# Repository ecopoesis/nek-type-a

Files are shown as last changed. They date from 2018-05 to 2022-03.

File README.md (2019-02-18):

# Natural Ergonomic Keyboard, Type A

One of the best keyboards ever made is the [Microsoft Natural Keyboard](https://en.wikipedia.org/wiki/Microsoft_Natural_Keyboard). 
Unfortunately modern versions of the natural keyboard are significantly worse then the original mid 90s versions. 
The goal of this project is to create a high-quality, open-source replacement for the natural keyboard.

Power by QMK

## Goals

* Standard split-QWERTY layout mirroring the Microsoft Natural Keyboards
* No built-in number pad
* High quality mechanical switches
* Bluetooth or USB connection
* Plug and play (no-solder) microcontroller replacement
* Heirloom quality

## Design

The keyboard (and repo) is divided into the following parts:

* Body
* Electronics

### Body

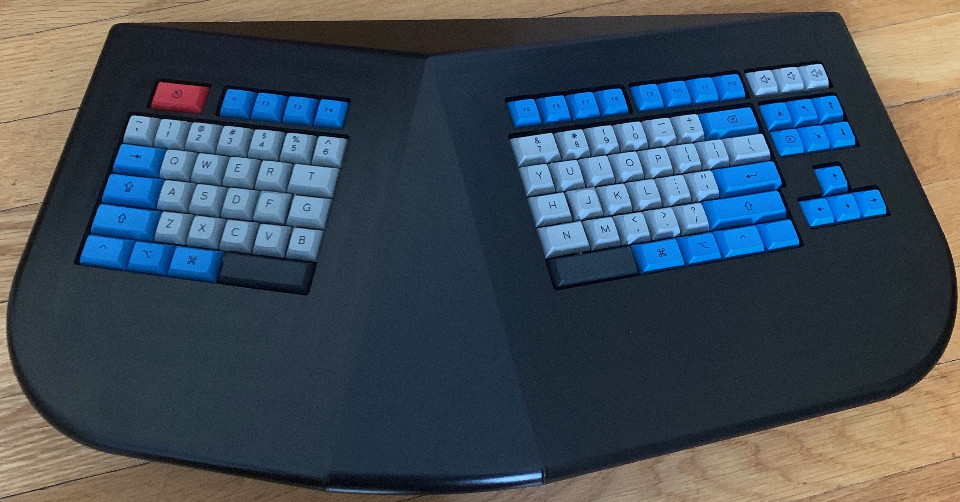
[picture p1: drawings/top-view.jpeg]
NEK Type A


The body has three major components: the aluminum unibody, the left and right steel switch plates and the acrylic access panel. 

Source files:
* `*.kbd.json` files are generated using the [keyboard_layout_editor.com](http://www.keyboard-layout-editor.com)
* `*.svg` and `*.dxf` files are built using [swillkb's Plate and Case Builder](http://builder.swillkb.com/) based on the `.kbd.json` files
  * The `*switch.*` files are the laser cutter templates
* `body.stl` and `body.step` are built from the [CadQuery](https://github.com/dcowden/cadquery) source file `body.py`. The easiest way to build this is to use the provided Docker image and `Makefile`:
  ```bash
    cd body && make
  ```    

You will need to have the following manufactured:
* Case
  * [`body.step`](body/target/body.step)
  * [screw tapping plan](drawings/bottom_view.pdf)
  * CNC from aluminum at [Xometry](http://xometry.com)
* Rubber gaskets
  * [`left_closed.dxf`](body/build_data/left_closed.dxf)
  * [`right_closed.dxf`](body/build_data/right_closed.dxf)
  * Laser cut from Buna-N Rubber 0.031 in at [Big Blue Saw](https://www.bigbluesaw.com/)
* Acrylic plate
  * [`plate.dxf`](drawings/plate.dxf)
  * Laser cut from Acrylic Plastic, Clear 0.118 in at [Big Blue Saw](https://www.bigbluesaw.com/)
* Steel plates
  * [`left_switch.dxf`](body/build_data/left_switch.dxf)
  * [`right_switch.dxf`](body/build_data/right_switch.dxf)
  * Laser cut from 304 Stainless Steel 1.5mm at [Lasergist](https://www.lasergist.com/)
  
You will need to buy:
* 8x M5x8mm screws
* 4x M5x20mm screws
* 3x M3 standoffs
* 3x M3x5mm screws
* 4x [M5 feet](https://www.amazon.com/gp/product/B000PWU9CC)
* 1x [USB-C panel mount](https://www.datapro.net/products/usb-c-panel-mount-extension-cable.html)
* 1x [19mm latching button](https://www.amazon.com/gp/product/B06XQZ3Y76)
* 1x [2-pin JST-XHP connector](https://www.amazon.com/gp/product/B0774TF39N)

### Electronics

The electronics are designed to be swappable. The left and right PCBs only contain the keyboard matrices and the ribbon connectors to the center PCB.

The PCBs can be made directly from the `BRD` files by [OSH Park](http://oshpark.com).

#### Left
[`left.brd`](eagle/nek-type-a/left.brd)

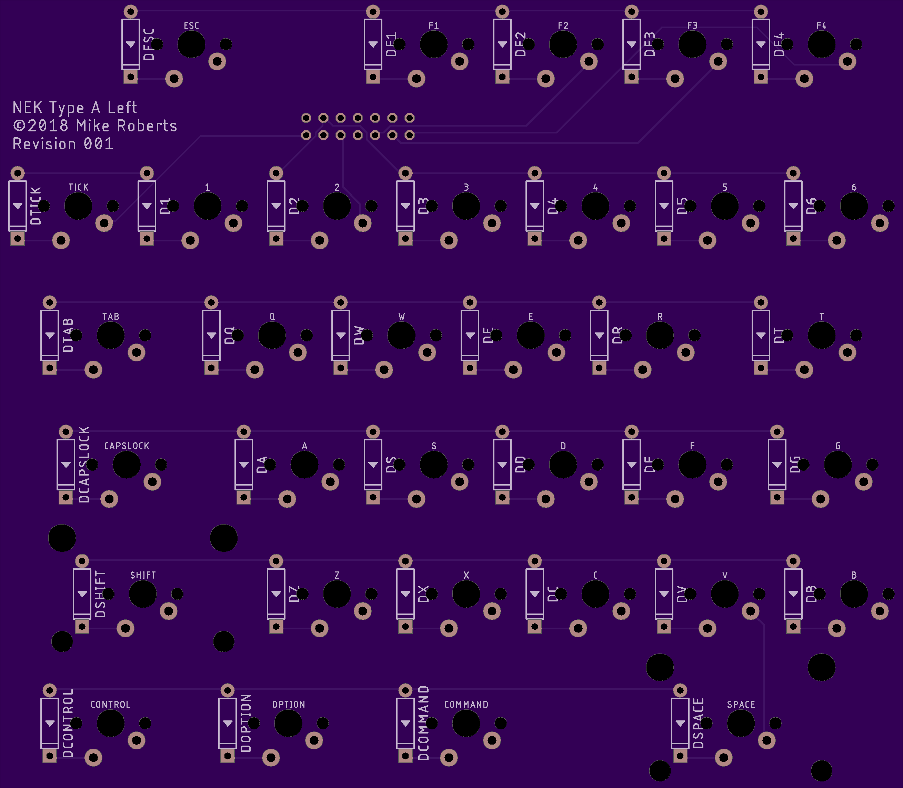
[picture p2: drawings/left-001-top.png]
Left PCB Rev 001 Top
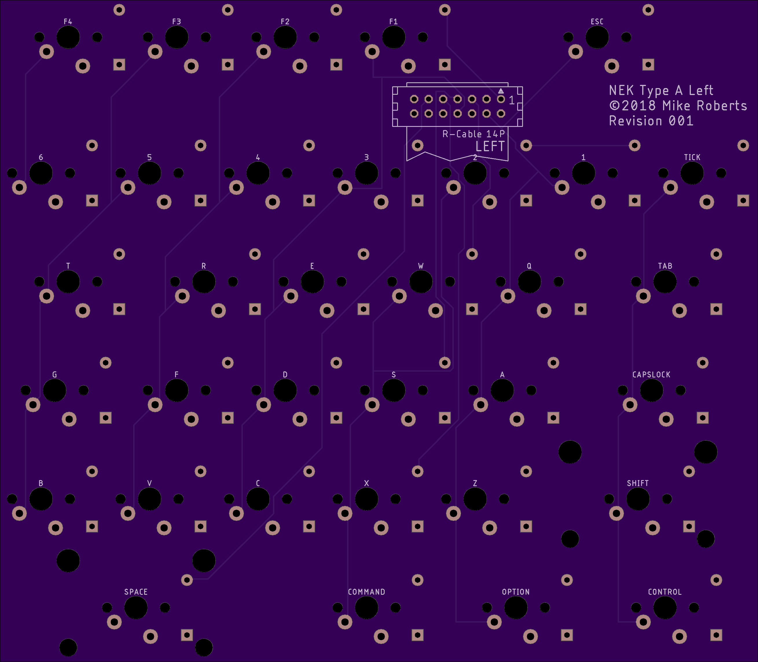
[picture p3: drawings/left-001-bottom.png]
Left PCB Rev 001 Bottom
 

#### Right
[`right.brd`](eagle/nek-type-a/right.brd)

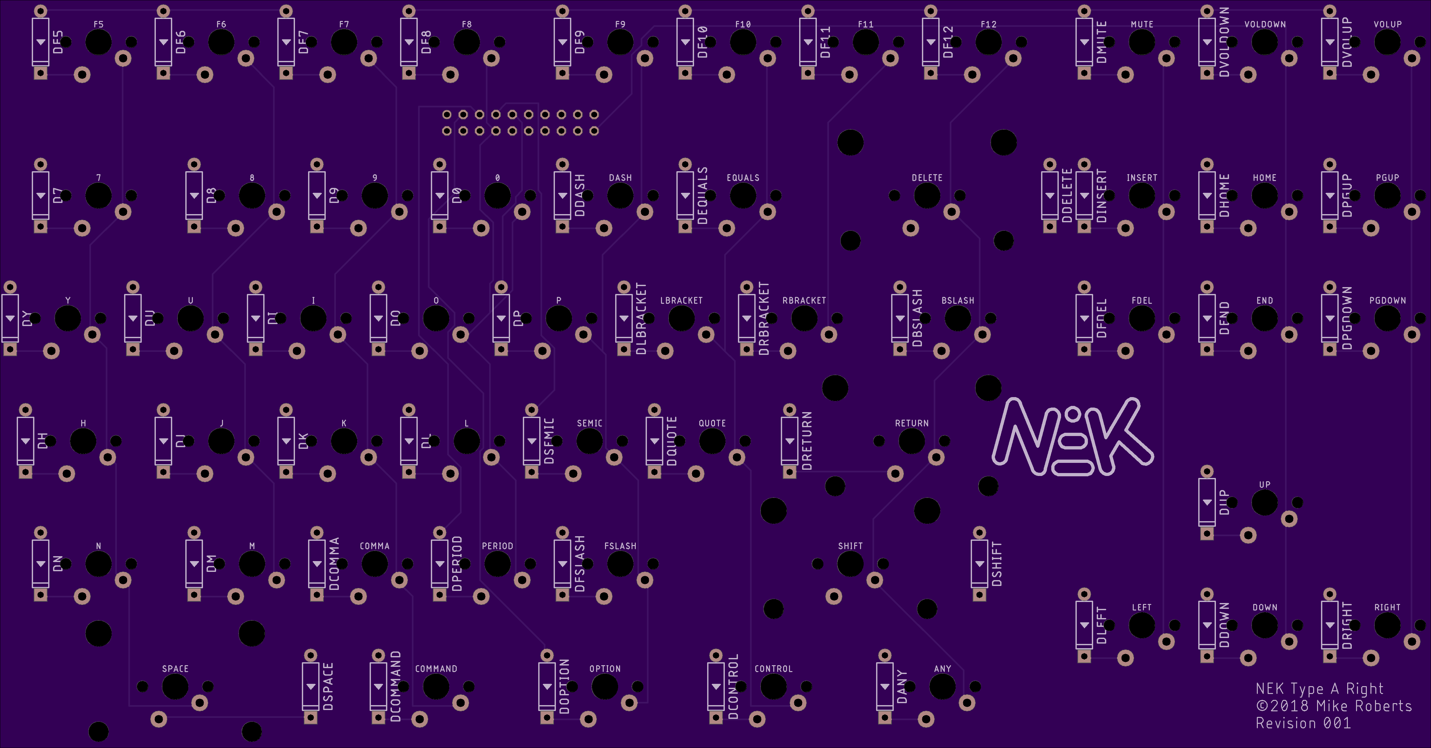
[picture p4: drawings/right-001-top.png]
Right PCB Rev 001 Top
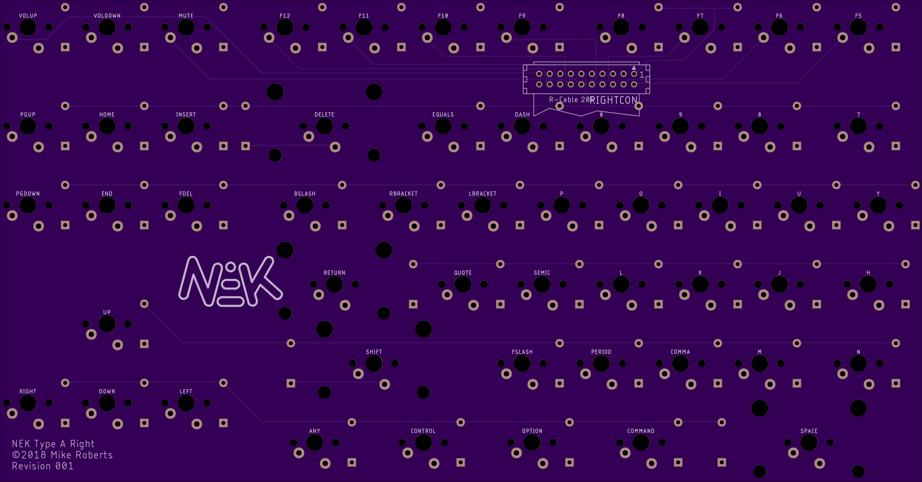
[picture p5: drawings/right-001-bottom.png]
Right PCB Rev 001 Bottom
 

#### Center
[`center.brd`](eagle/nek-type-a/center.brd)

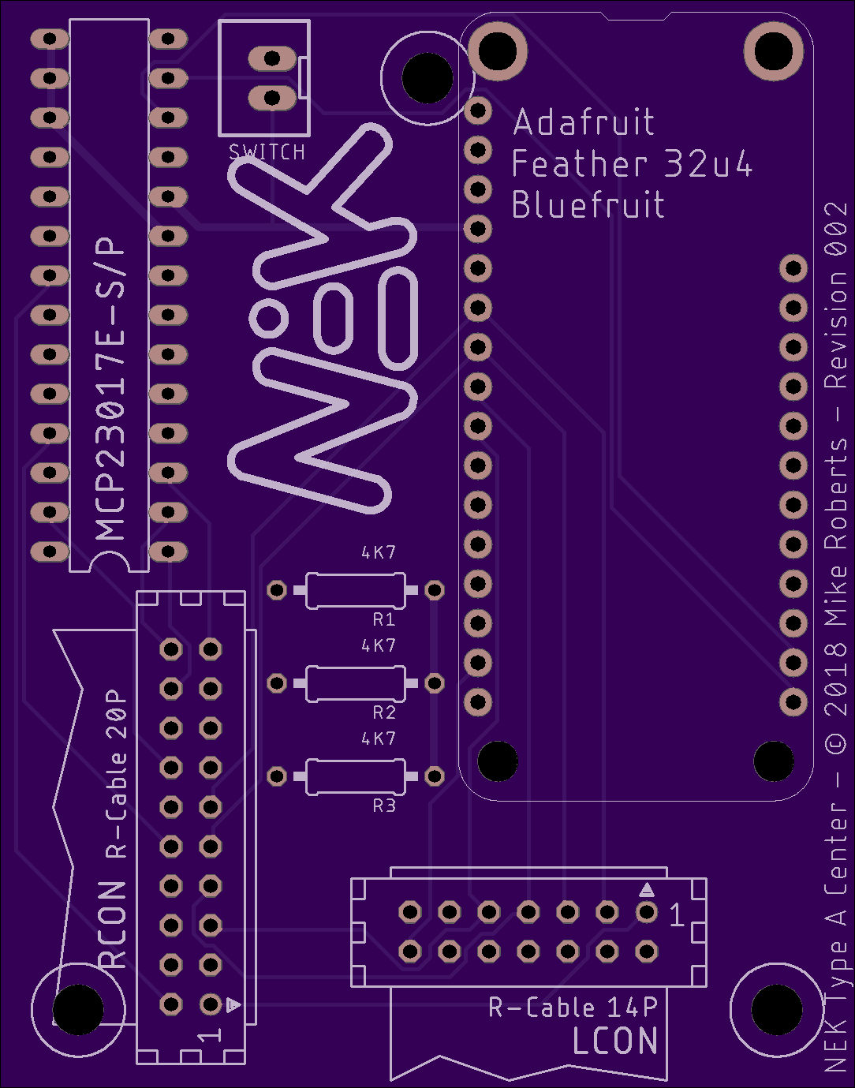
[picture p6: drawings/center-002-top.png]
Center PCB Rev 002 Top
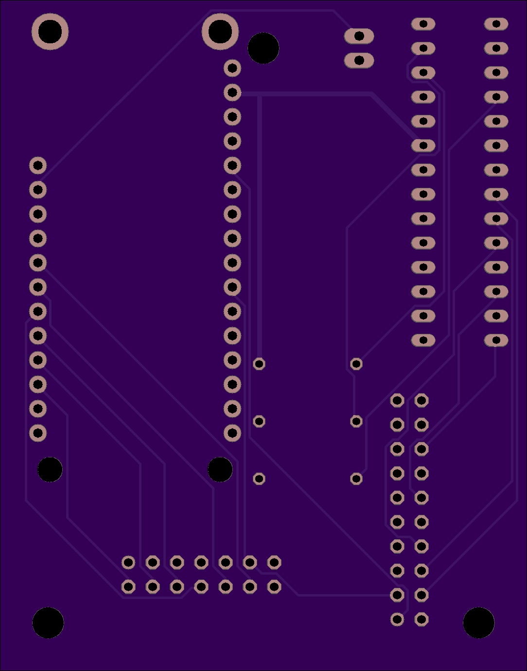
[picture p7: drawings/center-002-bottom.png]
Center PCB Rev 002 Bottom
 

The center PCB uses a [MCP23017E-S/P](https://www.microchip.com/wwwproducts/en/MCP23017) I/O expander hooked to the microprocessor via the I2C bus.
The center is designed to use development boards that conform the [Adafruit](https://www.adafruit.com/feather) interface. 
The Feather is connected via headers on the center PCB so it can be swapped for models with different connectivity in the future was standards evolve.

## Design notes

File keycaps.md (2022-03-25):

# Keycaps

Most keys are 1u. The non-1u keys are:

**1.25u**
- ⎇ (ALT) - x2
- H
- G
- BLANK (ANY)

**1.5u**
- ⌃ (CTRL) - x2
- ⌘ (CMD) - x2
- ⇥ (TAB)
- | (PIPE)
- T
- N
- 7/&

**1.75u**
- ⎋ (ESC)
- ⇪ (CAPSLOCK)

**2u**
- ⇧ (LSHIFT)
- ⌫ (BACKSPACE)

**2.25u**
- ↵ (ENTER)

**2.75u**
- SPACE
- ⇧ (RSHIFT)

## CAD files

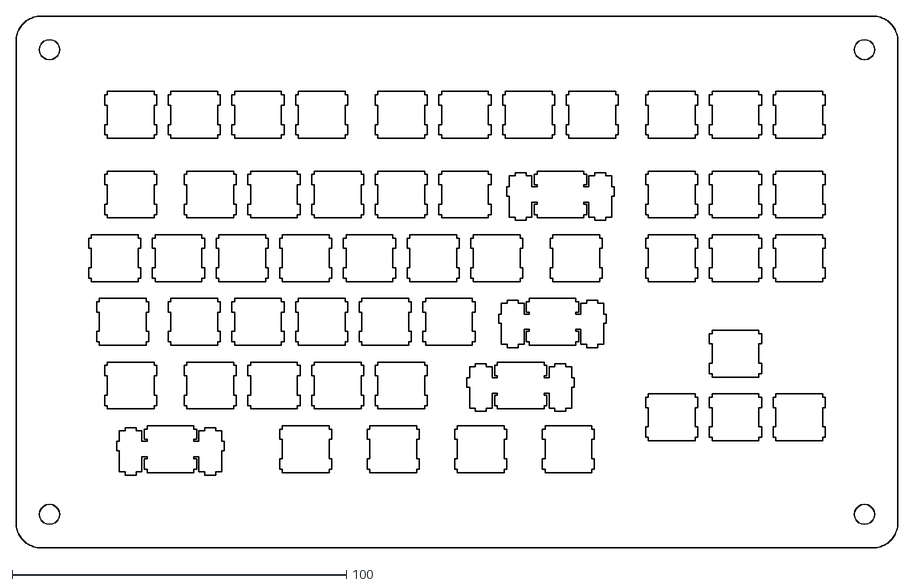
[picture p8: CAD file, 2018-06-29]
body/build_data/right_switch.dxf
263.8 x 159.1

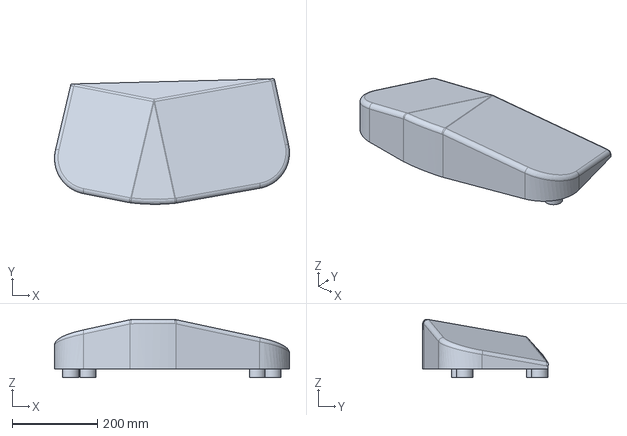
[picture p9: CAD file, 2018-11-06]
body/target/solid.step
552.2 x 295.2 x 137.2 mm

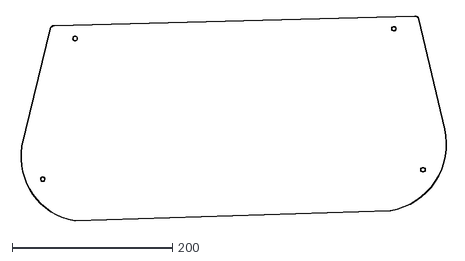
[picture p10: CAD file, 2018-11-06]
drawings/plate.dxf
540.4 x 255.9

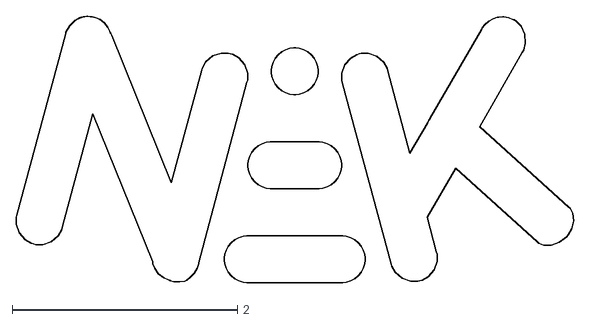
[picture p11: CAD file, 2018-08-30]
nek.dxf
4.95 x 2.36

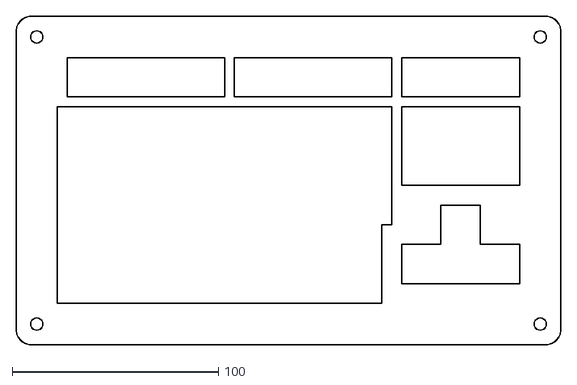
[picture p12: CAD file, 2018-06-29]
body/build_data/right_top.dxf
263.8 x 159.1

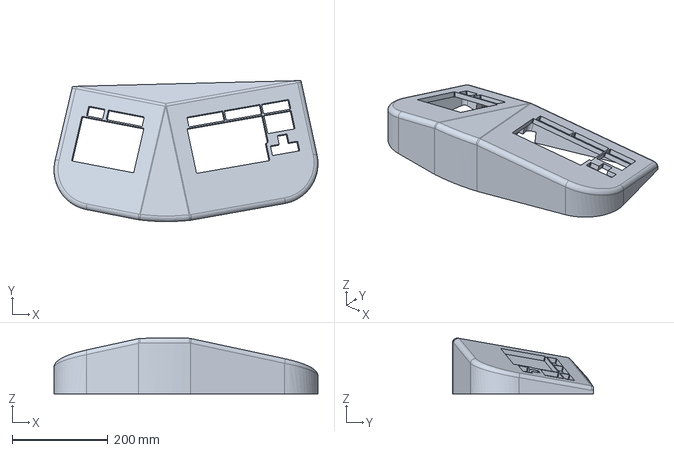
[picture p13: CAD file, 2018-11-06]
body/target/body.step
552.2 x 295.2 x 116.8 mm

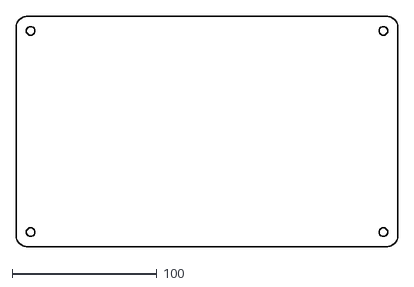
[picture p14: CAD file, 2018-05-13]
body/build_data/right_bottom.dxf
263.8 x 159.1

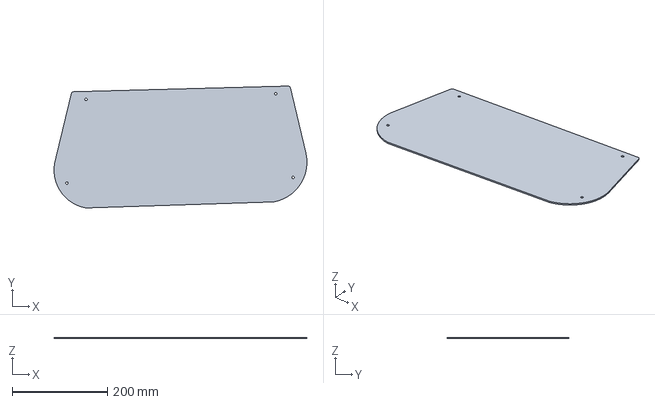
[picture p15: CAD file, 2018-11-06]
body/target/plate.step
531.0 x 255.9 x 3.00 mm

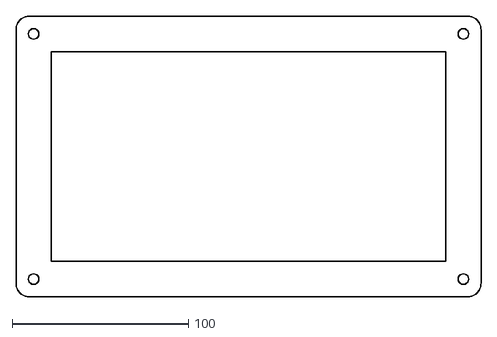
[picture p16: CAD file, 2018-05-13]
body/build_data/right_closed.dxf
263.8 x 159.1

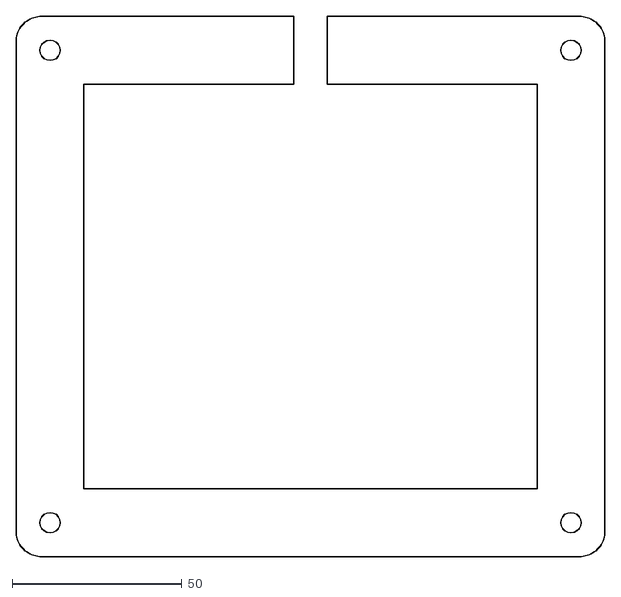
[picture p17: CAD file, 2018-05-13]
body/build_data/left_open.dxf
173.4 x 159.1

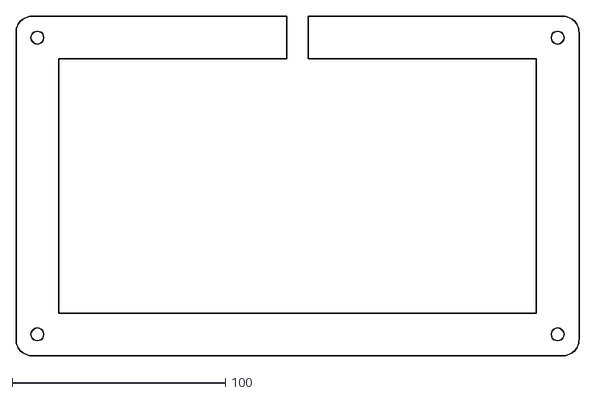
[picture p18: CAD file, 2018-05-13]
body/build_data/right_open.dxf
263.8 x 159.1

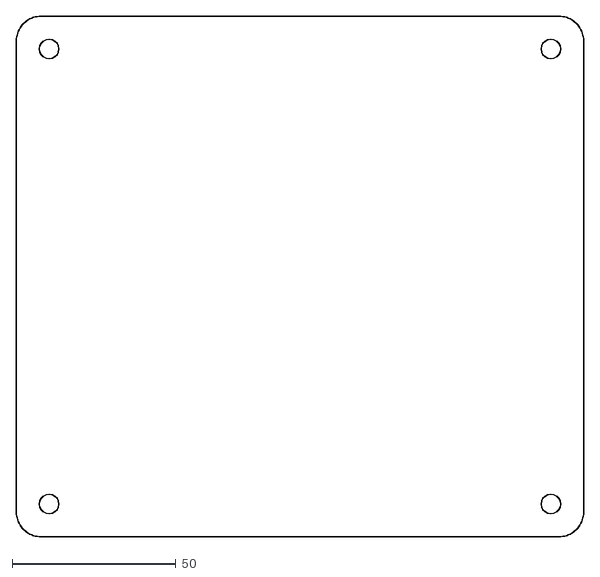
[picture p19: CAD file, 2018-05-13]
body/build_data/left_bottom.dxf
173.4 x 159.1

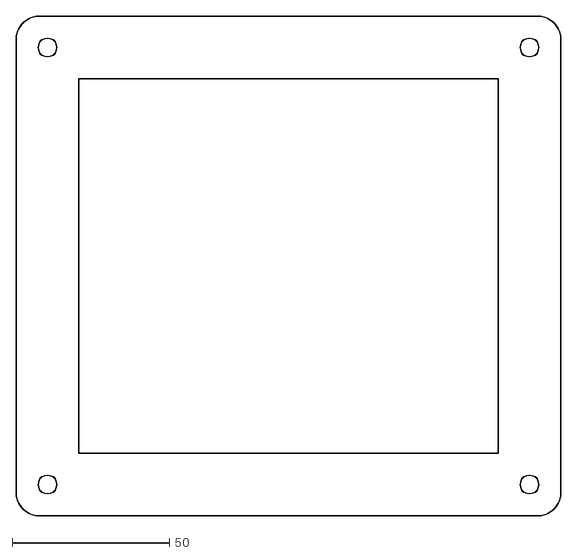
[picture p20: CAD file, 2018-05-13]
body/build_data/left_closed.dxf
173.4 x 159.1

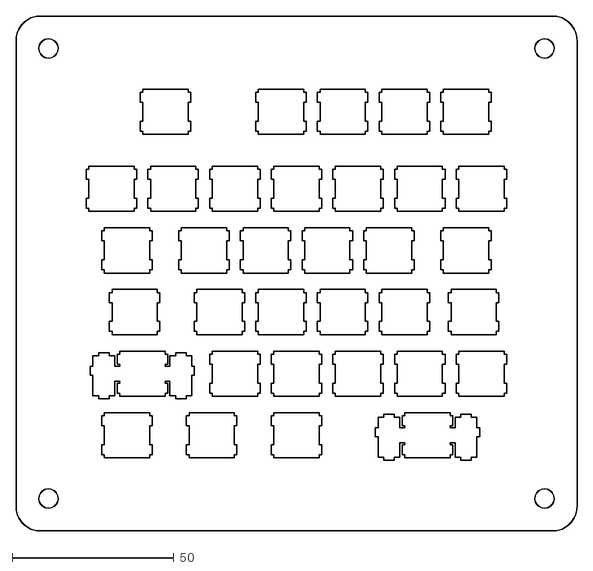
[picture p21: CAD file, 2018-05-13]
body/build_data/left_switch.dxf
173.4 x 159.1

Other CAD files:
body/build_data/left_top.dxf
body/target/body.stl
body/target/plate.stl
body/target/solid.stl

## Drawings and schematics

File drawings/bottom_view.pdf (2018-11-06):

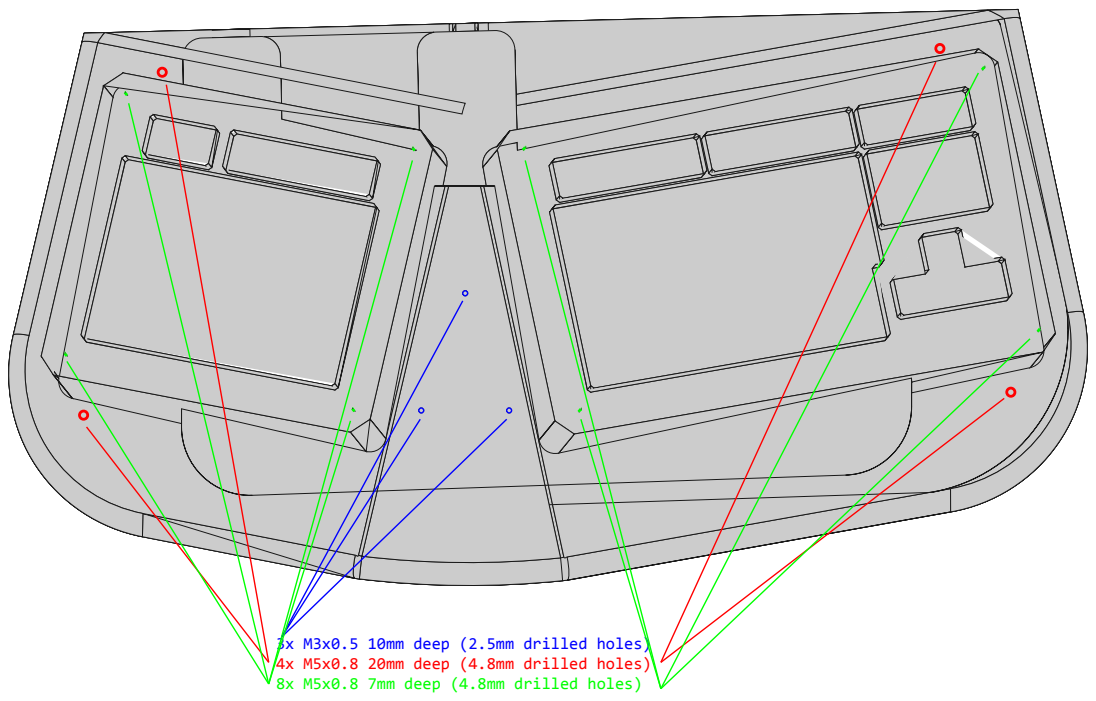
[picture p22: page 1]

3x M3x0.5 10mm deep (2.5mm drilled holes)
4x M5x0.8 20mm deep (4.8mm drilled holes)
8x M5x0.8 7mm deep (4.8mm drilled holes)

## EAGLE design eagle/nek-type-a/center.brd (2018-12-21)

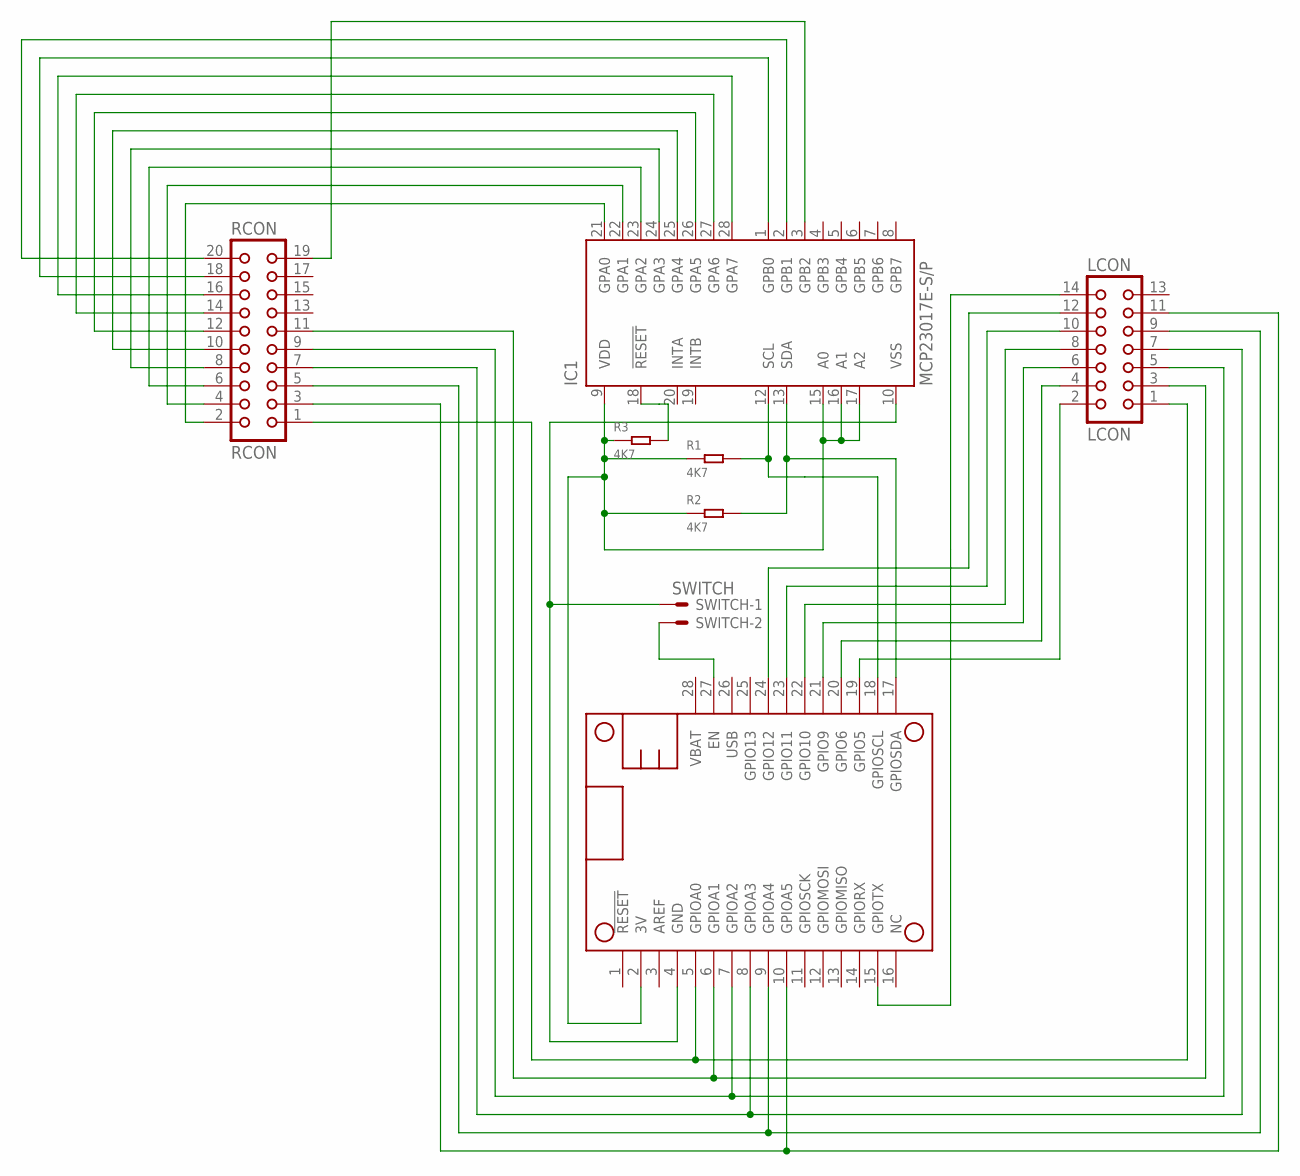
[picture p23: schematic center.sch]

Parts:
IC1: MCP23017E-S/P; DIL28-3
LCON: LCON; CON14
MS1: FEATHERWING_NODIM; FEATHERWING_DIM
R1, R2, R3: 4K7; PR-D2.3XL6.5MM
RCON: RCON; CON20
SWITCH: SWITCH; JST-XH-02-PACKAGE-LONG-PAD

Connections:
3V: IC1.9 (VDD), IC1.15 (A0), IC1.16 (A1), IC1.17 (A2), MS1.2 (3V), R1.1, R2.1, R3.1
EN: MS1.27 (EN), SWITCH.2
GND: IC1.10 (VSS), MS1.4 (GND), SWITCH.1
LCOL1: LCON.2, MS1.19 (GPIO5)
LCOL2: LCON.4, MS1.20 (GPIO6)
LCOL3: LCON.6, MS1.21 (GPIO9)
LCOL4: LCON.8, MS1.22 (GPIO10)
LCOL5: LCON.10, MS1.23 (GPIO11)
LCOL6: LCON.12, MS1.24 (GPIO12)
LCOL7: LCON.14, MS1.15 (GPIOTX)
RCOL1: IC1.21 (GPA0), RCON.2
RCOL2: IC1.22 (GPA1), RCON.4
RCOL3: IC1.23 (GPA2), RCON.6
RCOL4: IC1.24 (GPA3), RCON.8
RCOL5: IC1.25 (GPA4), RCON.10
RCOL6: IC1.26 (GPA5), RCON.12
RCOL7: IC1.27 (GPA6), RCON.14
RCOL8: IC1.28 (GPA7), RCON.16
RCOL9: IC1.1 (GPB0), RCON.18
RCOL10: IC1.2 (GPB1), RCON.20
RCOL11: IC1.3 (GPB2), RCON.19
RESET: IC1.18 (!RESET), R3.2
ROW1: LCON.1, MS1.5 (GPIOA0), RCON.1
ROW2: LCON.3, MS1.6 (GPIOA1), RCON.11
ROW3: LCON.5, MS1.7 (GPIOA2), RCON.9
ROW4: LCON.7, MS1.8 (GPIOA3), RCON.7
ROW5: LCON.9, MS1.9 (GPIOA4), RCON.5
ROW6: LCON.11, MS1.10 (GPIOA5), RCON.3
SCL: IC1.12 (SCL), MS1.18 (GPIOSCL), R1.2
SDA: IC1.13 (SDA), MS1.17 (GPIOSDA), R2.2

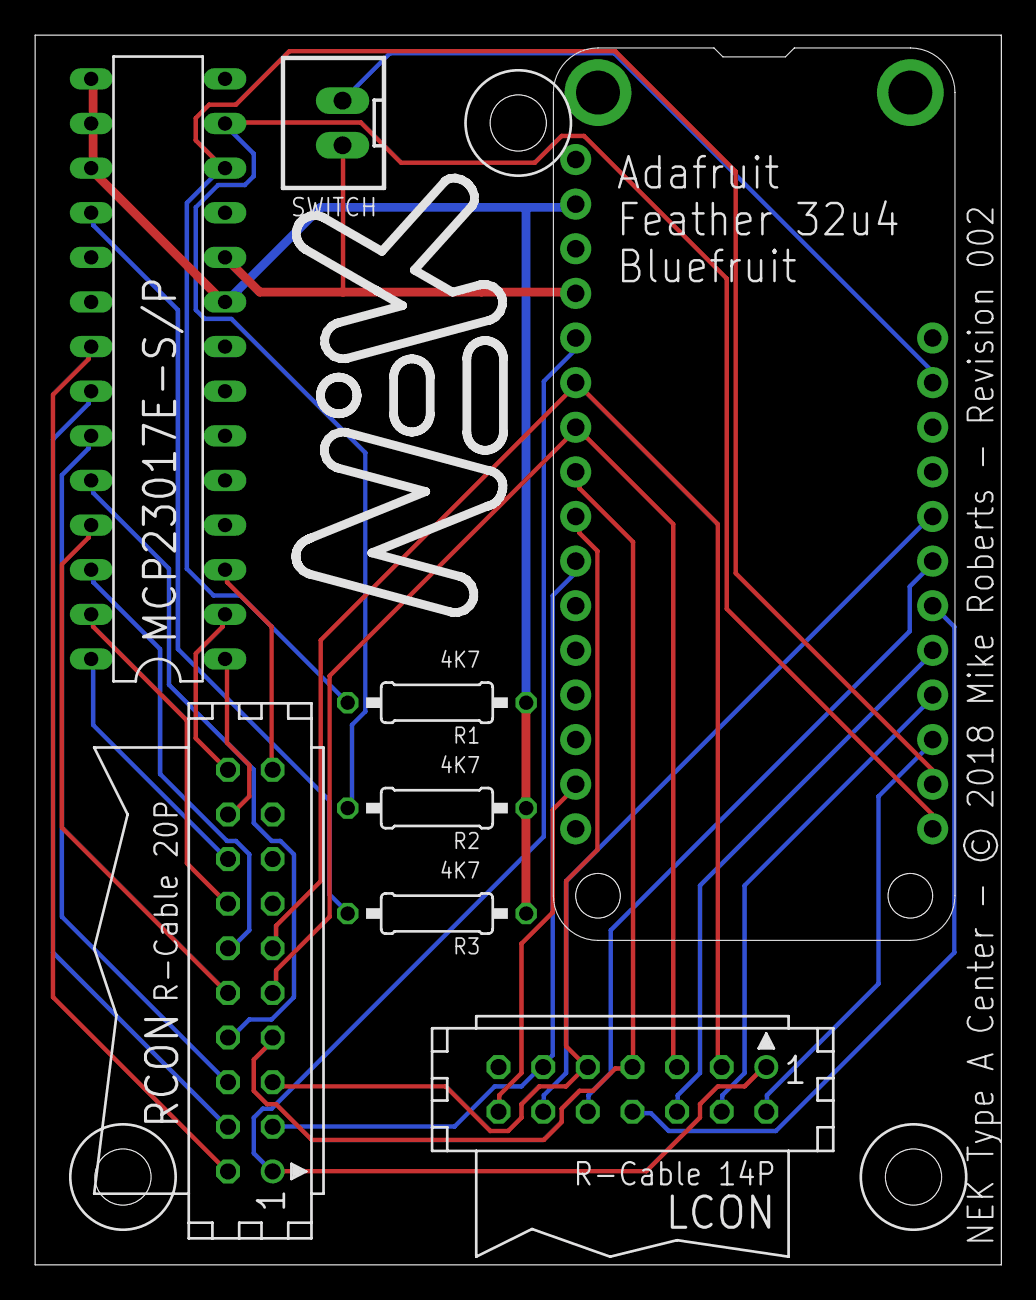
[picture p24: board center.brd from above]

Board: 2 copper layers, 55.0 x 70.0 mm, 8 parts (0 on the bottom side), 30 nets.

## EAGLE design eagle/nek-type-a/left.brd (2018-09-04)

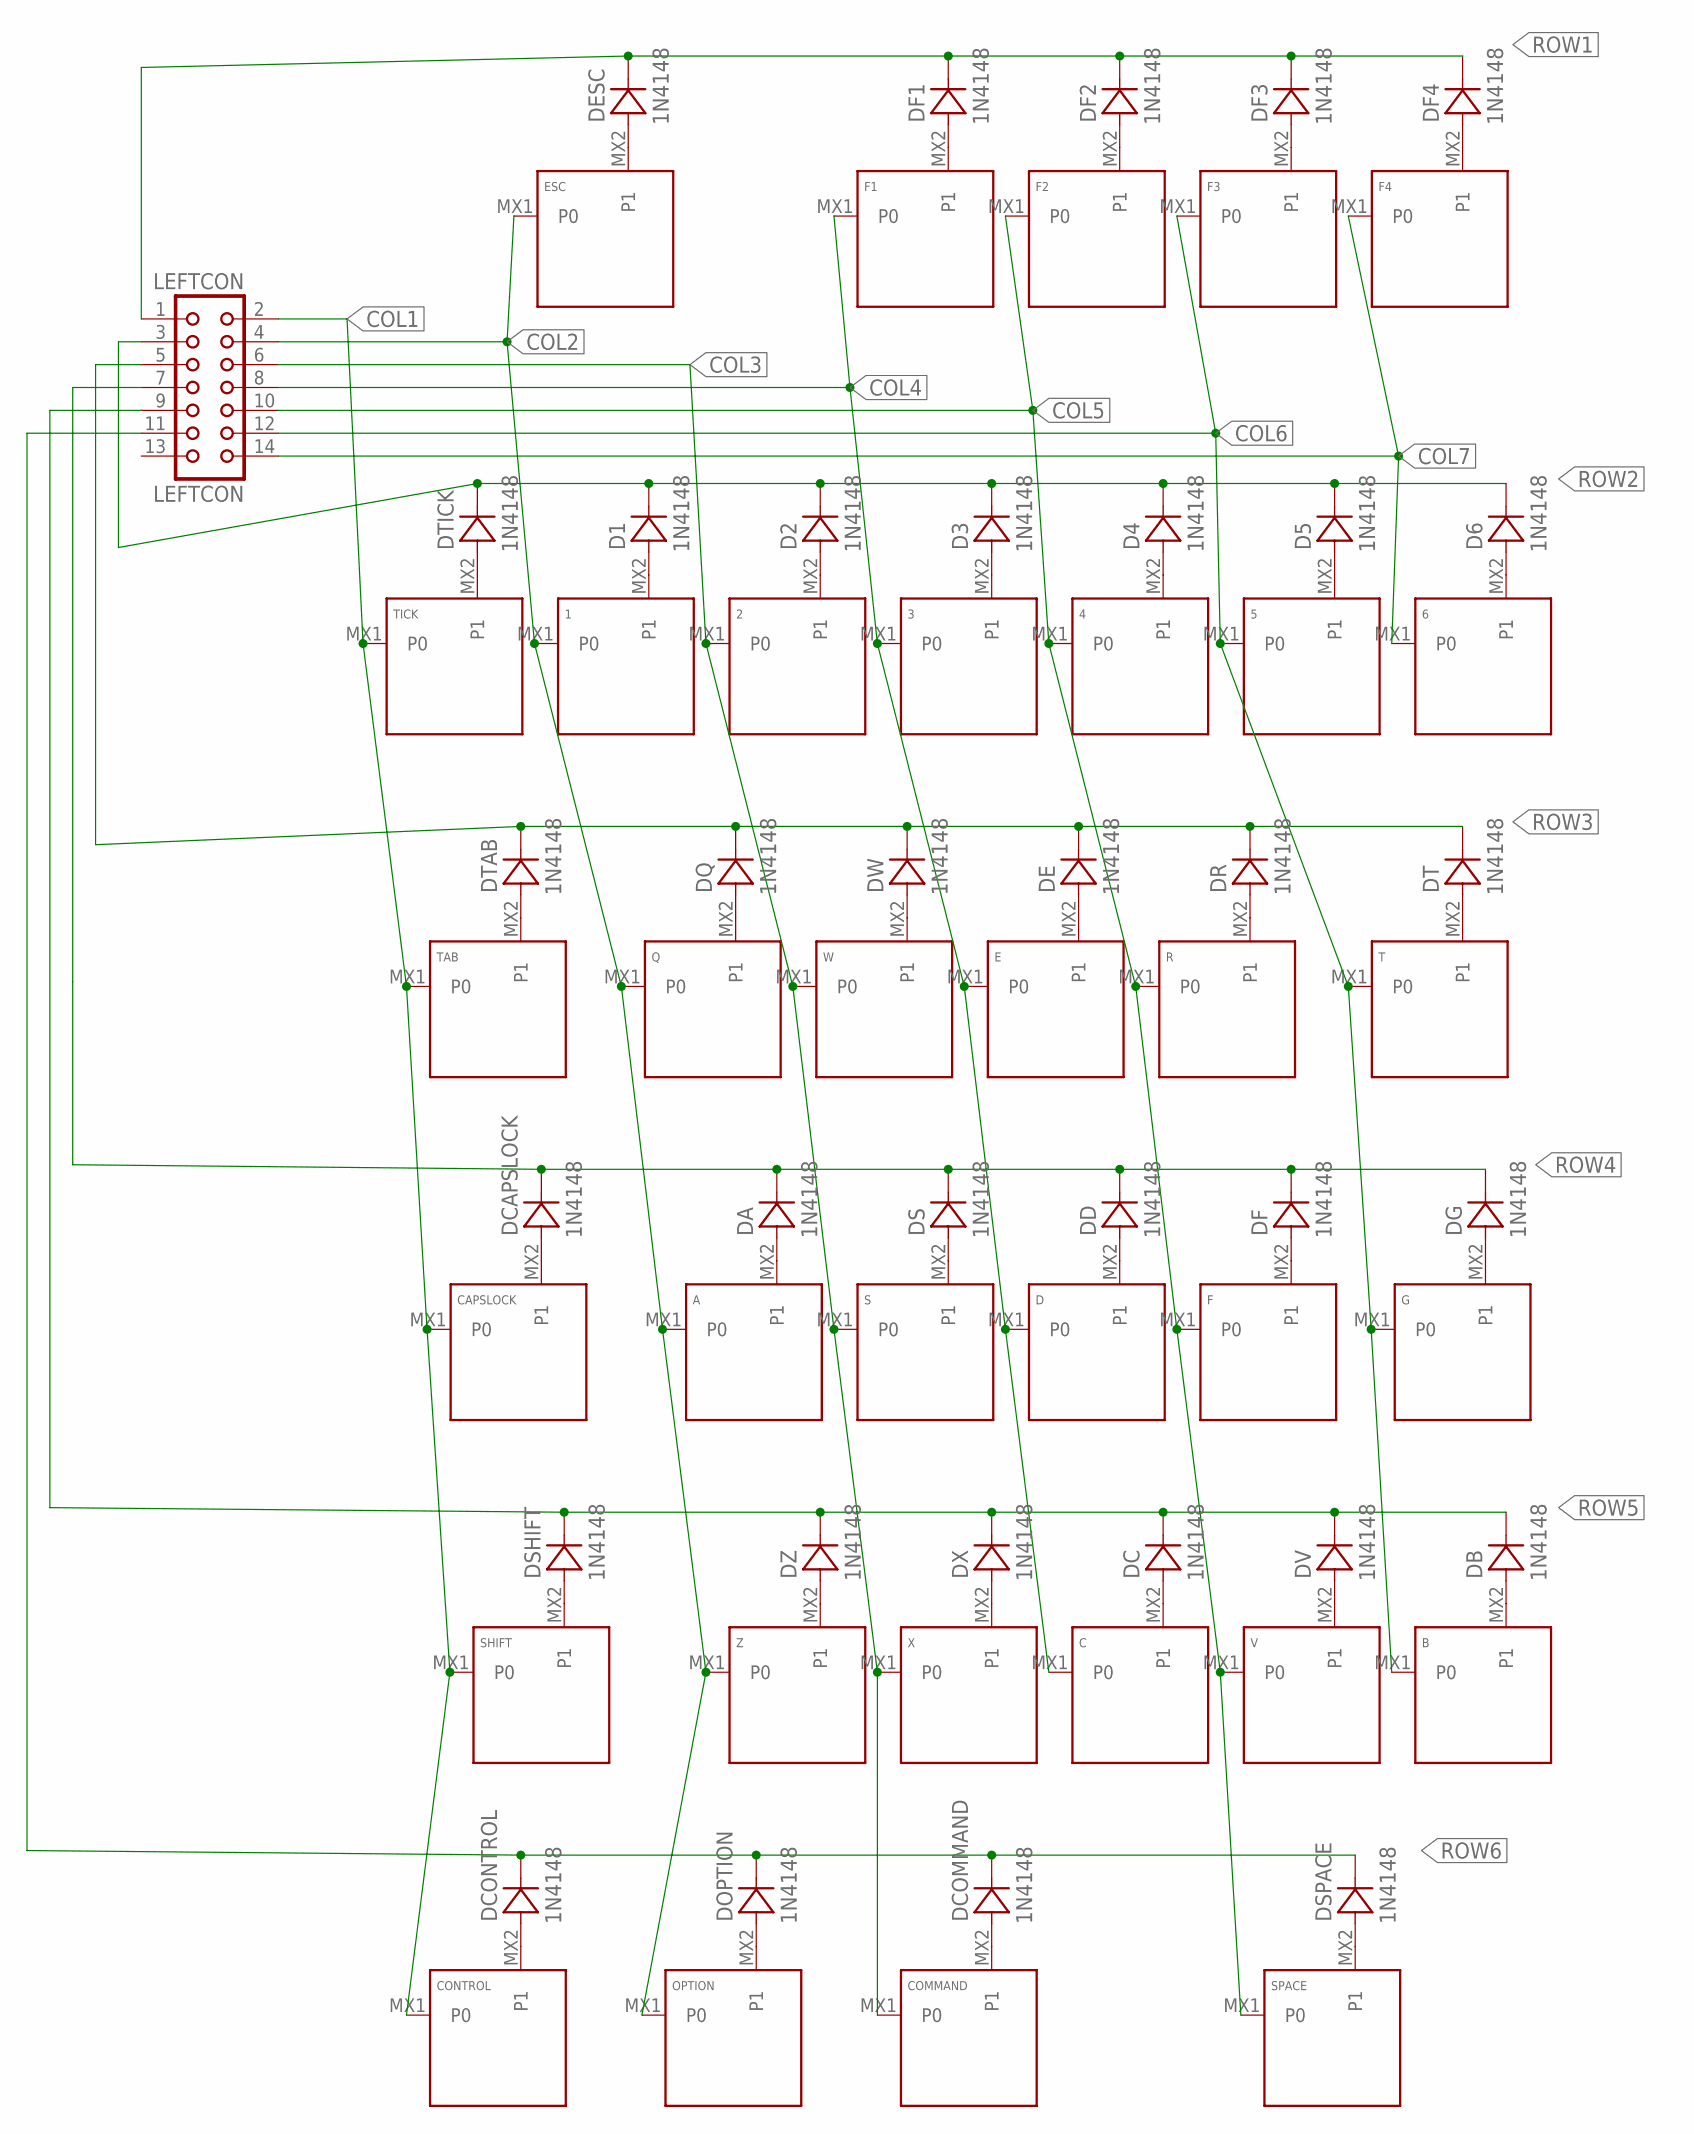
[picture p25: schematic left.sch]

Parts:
1, 2, 3, 4, 5, 6: KEYSWITCH-PLAIN-MX-1U; MX-1U
A: KEYSWITCH-PLAIN-MX-1U; MX-1U
B: KEYSWITCH-PLAIN-MX-1U; MX-1U
C: KEYSWITCH-PLAIN-MX-1U; MX-1U
CAPSLOCK: KEYSWITCH-PLAIN-MX-1U; MX-1U
COMMAND: KEYSWITCH-PLAIN-MX-1U; MX-1U
CONTROL: KEYSWITCH-PLAIN-MX-1U; MX-1U
D: KEYSWITCH-PLAIN-MX-1U; MX-1U
D1, D2, D3, D4, D5, D6: 1N4148; DO-35
DA: 1N4148; DO-35
DB: 1N4148; DO-35
DC: 1N4148; DO-35
DCAPSLOCK: 1N4148; DO-35
DCOMMAND: 1N4148; DO-35
DCONTROL: 1N4148; DO-35
DD: 1N4148; DO-35
DE: 1N4148; DO-35
DESC: 1N4148; DO-35
DF, DF1, DF2, DF3, DF4: 1N4148; DO-35
DG: 1N4148; DO-35
DOPTION: 1N4148; DO-35
DQ: 1N4148; DO-35
DR: 1N4148; DO-35
DS: 1N4148; DO-35
DSHIFT: 1N4148; DO-35
DSPACE: 1N4148; DO-35
DT: 1N4148; DO-35
DTAB: 1N4148; DO-35
DTICK: 1N4148; DO-35
DV: 1N4148; DO-35
DW: 1N4148; DO-35
DX: 1N4148; DO-35
DZ: 1N4148; DO-35
E: KEYSWITCH-PLAIN-MX-1U; MX-1U
ESC: KEYSWITCH-PLAIN-MX-1U; MX-1U
F, F1, F2, F3, F4: KEYSWITCH-PLAIN-MX-1U; MX-1U
G: KEYSWITCH-PLAIN-MX-1U; MX-1U
LEFTCON: LEFTCON; CON14
OPTION: KEYSWITCH-PLAIN-MX-1U; MX-1U
Q: KEYSWITCH-PLAIN-MX-1U; MX-1U
R: KEYSWITCH-PLAIN-MX-1U; MX-1U
S: KEYSWITCH-PLAIN-MX-1U; MX-1U
SHIFT: KEYSWITCH-PLAIN-MX-2U; MX-2U
SPACE: KEYSWITCH-PLAIN-MX-2U; MX-2U
T: KEYSWITCH-PLAIN-MX-1U; MX-1U
TAB: KEYSWITCH-PLAIN-MX-1U; MX-1U
TICK: KEYSWITCH-PLAIN-MX-1U; MX-1U
V: KEYSWITCH-PLAIN-MX-1U; MX-1U
W: KEYSWITCH-PLAIN-MX-1U; MX-1U
X: KEYSWITCH-PLAIN-MX-1U; MX-1U
Z: KEYSWITCH-PLAIN-MX-1U; MX-1U

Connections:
COL1: CAPSLOCK.MX1 (P0), CONTROL.MX1 (P0), LEFTCON.2, SHIFT.MX1 (P0), TAB.MX1 (P0), TICK.MX1 (P0)
COL2: 1.MX1 (P0), A.MX1 (P0), ESC.MX1 (P0), LEFTCON.4, OPTION.MX1 (P0), Q.MX1 (P0), Z.MX1 (P0)
COL3: 2.MX1 (P0), COMMAND.MX1 (P0), LEFTCON.6, S.MX1 (P0), W.MX1 (P0), X.MX1 (P0)
COL4: 3.MX1 (P0), C.MX1 (P0), D.MX1 (P0), E.MX1 (P0), F1.MX1 (P0), LEFTCON.8
COL5: 4.MX1 (P0), F.MX1 (P0), F2.MX1 (P0), LEFTCON.10, R.MX1 (P0), SPACE.MX1 (P0), V.MX1 (P0)
COL6: 5.MX1 (P0), B.MX1 (P0), F3.MX1 (P0), G.MX1 (P0), LEFTCON.12, T.MX1 (P0)
COL7: 6.MX1 (P0), F4.MX1 (P0), LEFTCON.14
unnamed: DESC.A, ESC.MX2 (P1)
unnamed: DF1.A, F1.MX2 (P1)
unnamed: DF2.A, F2.MX2 (P1)
unnamed: DF3.A, F3.MX2 (P1)
unnamed: DF4.A, F4.MX2 (P1)
unnamed: 6.MX2 (P1), D6.A
unnamed: 5.MX2 (P1), D5.A
unnamed: 4.MX2 (P1), D4.A
unnamed: 3.MX2 (P1), D3.A
unnamed: 2.MX2 (P1), D2.A
unnamed: 1.MX2 (P1), D1.A
unnamed: DTICK.A, TICK.MX2 (P1)
unnamed: DTAB.A, TAB.MX2 (P1)
unnamed: DQ.A, Q.MX2 (P1)
unnamed: DW.A, W.MX2 (P1)
unnamed: DE.A, E.MX2 (P1)
unnamed: DR.A, R.MX2 (P1)
unnamed: DT.A, T.MX2 (P1)
unnamed: CAPSLOCK.MX2 (P1), DCAPSLOCK.A
unnamed: A.MX2 (P1), DA.A
unnamed: DS.A, S.MX2 (P1)
unnamed: D.MX2 (P1), DD.A
unnamed: DF.A, F.MX2 (P1)
unnamed: DG.A, G.MX2 (P1)
unnamed: DSHIFT.A, SHIFT.MX2 (P1)
unnamed: DZ.A, Z.MX2 (P1)
unnamed: DX.A, X.MX2 (P1)
unnamed: C.MX2 (P1), DC.A
unnamed: DV.A, V.MX2 (P1)
unnamed: B.MX2 (P1), DB.A
unnamed: DSPACE.A, SPACE.MX2 (P1)
unnamed: COMMAND.MX2 (P1), DCOMMAND.A
unnamed: DOPTION.A, OPTION.MX2 (P1)
unnamed: CONTROL.MX2 (P1), DCONTROL.A
ROW1: DESC.C, DF1.C, DF2.C, DF3.C, DF4.C, LEFTCON.1
ROW2: D1.C, D2.C, D3.C, D4.C, D5.C, D6.C, DTICK.C, LEFTCON.3
ROW3: DE.C, DQ.C, DR.C, DT.C, DTAB.C, DW.C, LEFTCON.5
ROW4: DA.C, DCAPSLOCK.C, DD.C, DF.C, DG.C, DS.C, LEFTCON.7
ROW5: DB.C, DC.C, DSHIFT.C, DV.C, DX.C, DZ.C, LEFTCON.9
ROW6: DCOMMAND.C, DCONTROL.C, DOPTION.C, DSPACE.C, LEFTCON.11

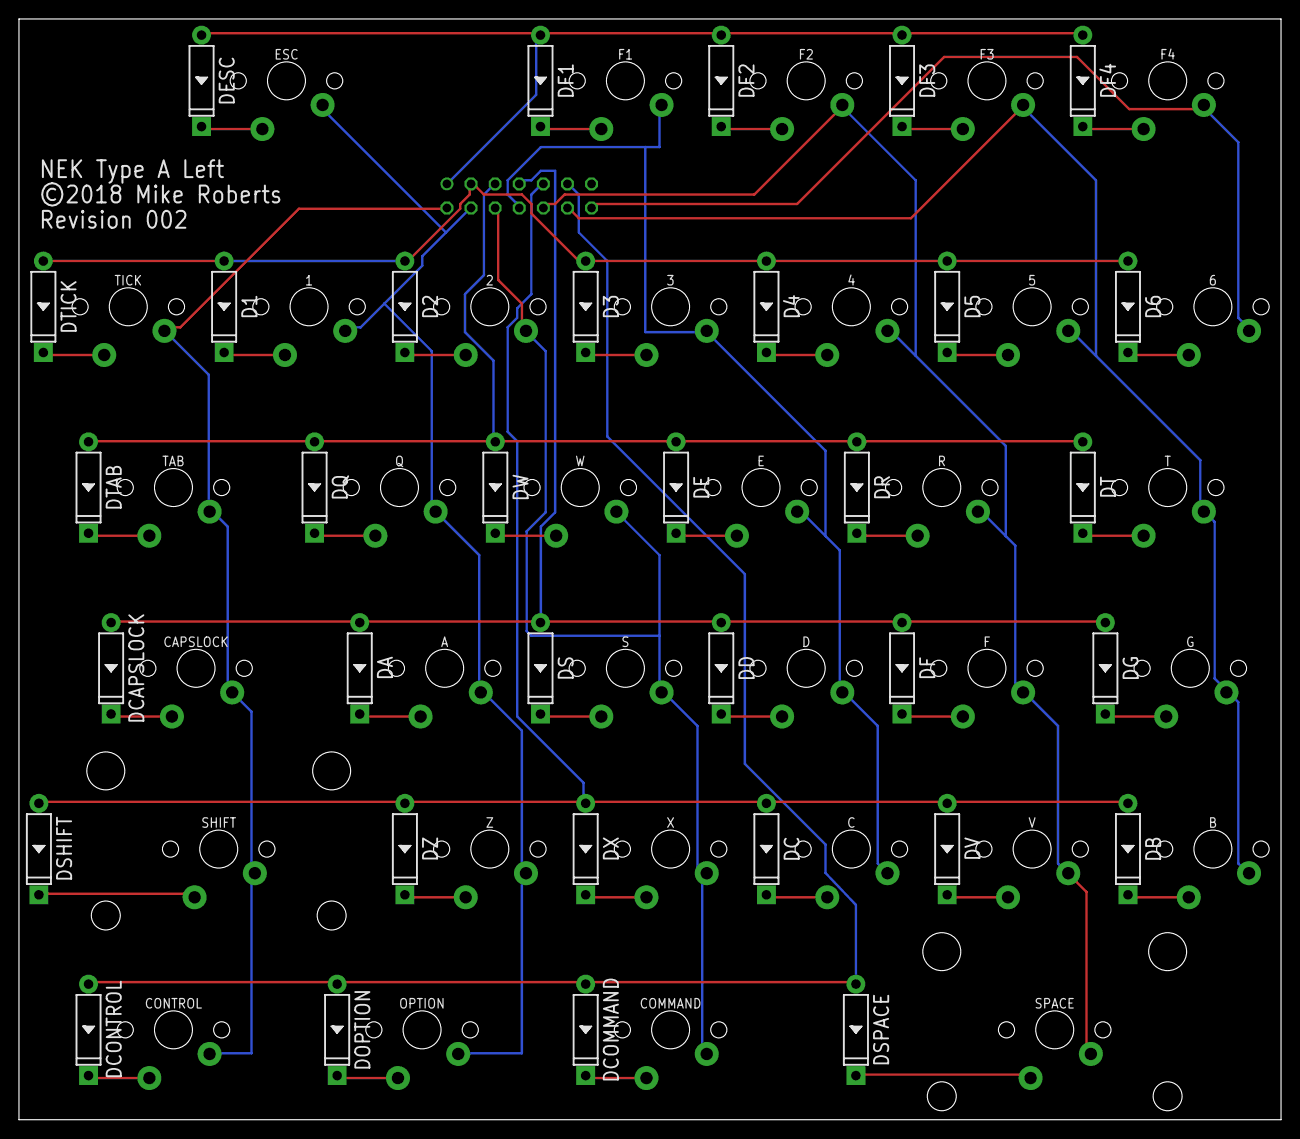
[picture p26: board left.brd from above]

Board: 2 copper layers, 133.0 x 116.0 mm, 69 parts (1 on the bottom side), 47 nets.

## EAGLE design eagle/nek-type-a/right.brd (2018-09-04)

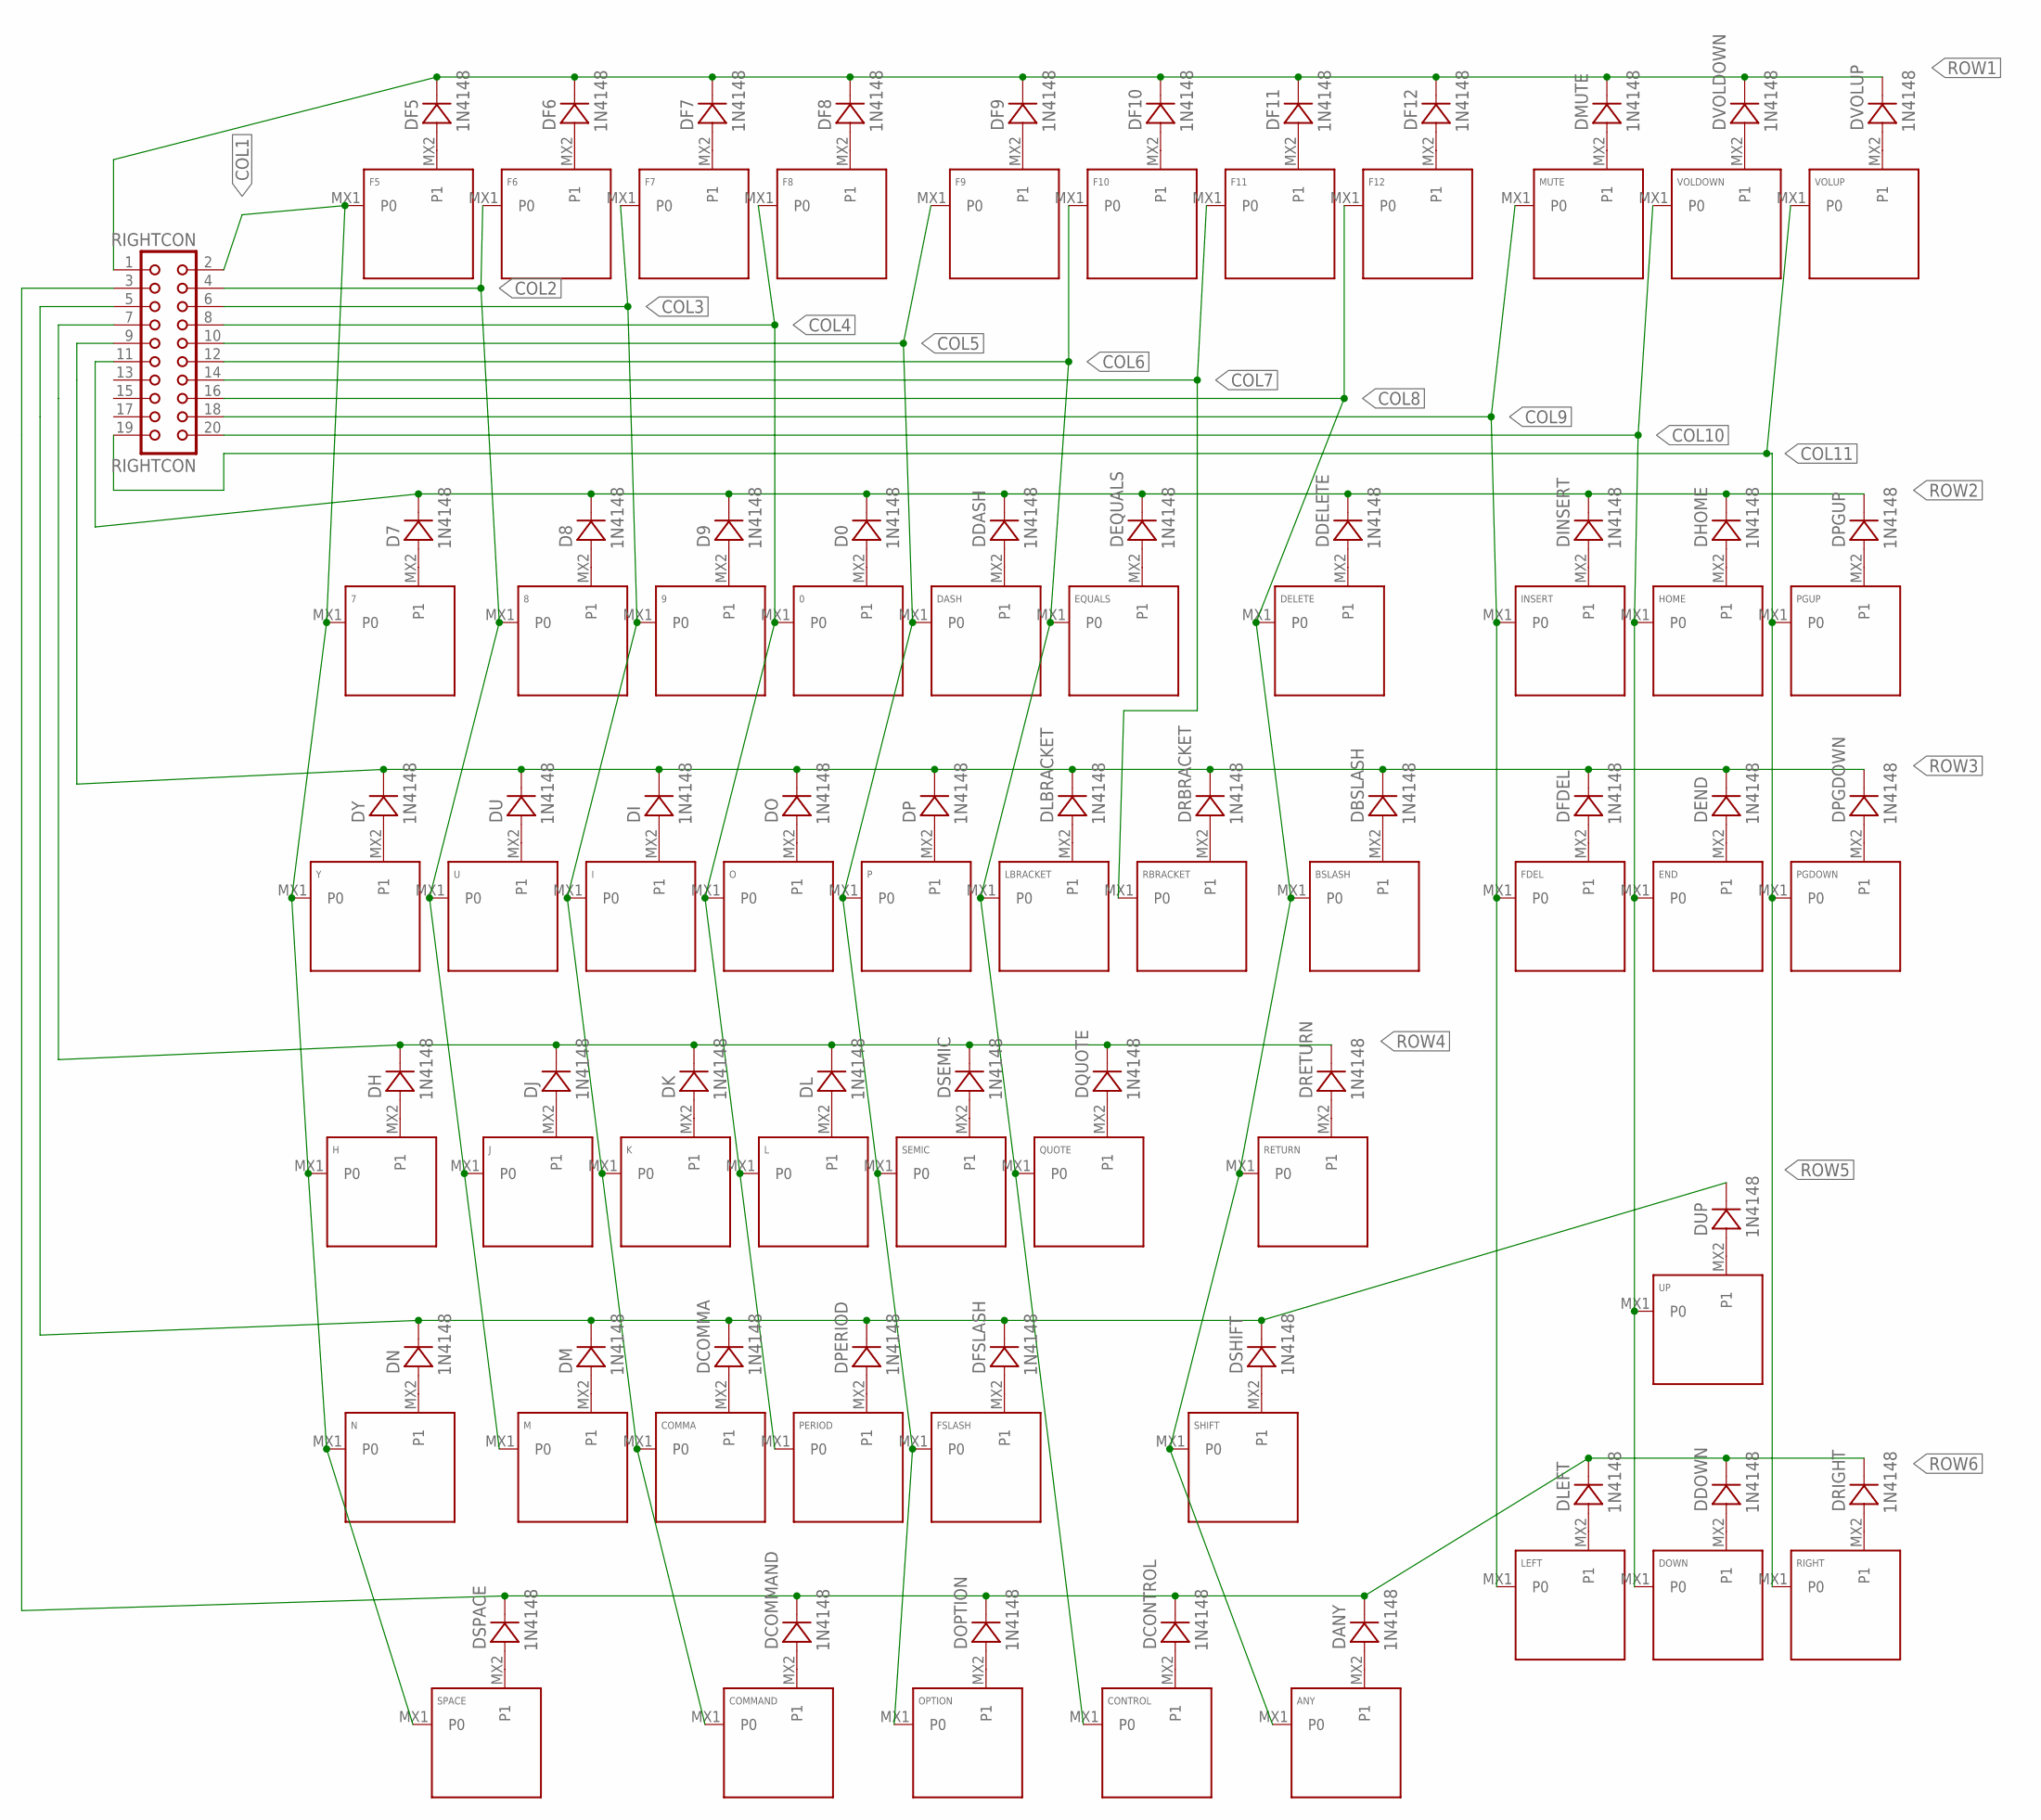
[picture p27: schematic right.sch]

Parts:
0, 7, 8, 9: KEYSWITCH-PLAIN-MX-1U; MX-1U
ANY: KEYSWITCH-PLAIN-MX-1U; MX-1U
BSLASH: KEYSWITCH-PLAIN-MX-1U; MX-1U
COMMA: KEYSWITCH-PLAIN-MX-1U; MX-1U
COMMAND: KEYSWITCH-PLAIN-MX-1U; MX-1U
CONTROL: KEYSWITCH-PLAIN-MX-1U; MX-1U
D0, D7, D8, D9: 1N4148; DO-35
DANY: 1N4148; DO-35
DASH: KEYSWITCH-PLAIN-MX-1U; MX-1U
DBSLASH: 1N4148; DO-35
DCOMMA: 1N4148; DO-35
DCOMMAND: 1N4148; DO-35
DCONTROL: 1N4148; DO-35
DDASH: 1N4148; DO-35
DDELETE: 1N4148; DO-35
DDOWN: 1N4148; DO-35
DELETE: KEYSWITCH-PLAIN-MX-2U; MX-2U
DEND: 1N4148; DO-35
DEQUALS: 1N4148; DO-35
DF5, DF6, DF7, DF8, DF9, DF10, DF11, DF12: 1N4148; DO-35
DFDEL: 1N4148; DO-35
DFSLASH: 1N4148; DO-35
DH: 1N4148; DO-35
DHOME: 1N4148; DO-35
DI: 1N4148; DO-35
DINSERT: 1N4148; DO-35
DJ: 1N4148; DO-35
DK: 1N4148; DO-35
DL: 1N4148; DO-35
DLBRACKET: 1N4148; DO-35
DLEFT: 1N4148; DO-35
DM: 1N4148; DO-35
DMUTE: 1N4148; DO-35
DN: 1N4148; DO-35
DO: 1N4148; DO-35
DOPTION: 1N4148; DO-35
DOWN: KEYSWITCH-PLAIN-MX-1U; MX-1U
DP: 1N4148; DO-35
DPERIOD: 1N4148; DO-35
DPGDOWN: 1N4148; DO-35
DPGUP: 1N4148; DO-35
DQUOTE: 1N4148; DO-35
DRBRACKET: 1N4148; DO-35
DRETURN: 1N4148; DO-35
DRIGHT: 1N4148; DO-35
DSEMIC: 1N4148; DO-35
DSHIFT: 1N4148; DO-35
DSPACE: 1N4148; DO-35
DU: 1N4148; DO-35
DUP: 1N4148; DO-35
DVOLDOWN: 1N4148; DO-35
DVOLUP: 1N4148; DO-35
DY: 1N4148; DO-35
END: KEYSWITCH-PLAIN-MX-1U; MX-1U
EQUALS: KEYSWITCH-PLAIN-MX-1U; MX-1U
F5, F6, F7, F8, F9, F10, F11, F12: KEYSWITCH-PLAIN-MX-1U; MX-1U
FDEL: KEYSWITCH-PLAIN-MX-1U; MX-1U
FSLASH: KEYSWITCH-PLAIN-MX-1U; MX-1U
H: KEYSWITCH-PLAIN-MX-1U; MX-1U
HOME: KEYSWITCH-PLAIN-MX-1U; MX-1U
I: KEYSWITCH-PLAIN-MX-1U; MX-1U
INSERT: KEYSWITCH-PLAIN-MX-1U; MX-1U
J: KEYSWITCH-PLAIN-MX-1U; MX-1U
K: KEYSWITCH-PLAIN-MX-1U; MX-1U
L: KEYSWITCH-PLAIN-MX-1U; MX-1U
LBRACKET: KEYSWITCH-PLAIN-MX-1U; MX-1U
LEFT: KEYSWITCH-PLAIN-MX-1U; MX-1U
M: KEYSWITCH-PLAIN-MX-1U; MX-1U
MUTE: KEYSWITCH-PLAIN-MX-1U; MX-1U
N: KEYSWITCH-PLAIN-MX-1U; MX-1U
O: KEYSWITCH-PLAIN-MX-1U; MX-1U
OPTION: KEYSWITCH-PLAIN-MX-1U; MX-1U
P: KEYSWITCH-PLAIN-MX-1U; MX-1U
PERIOD: KEYSWITCH-PLAIN-MX-1U; MX-1U
PGDOWN: KEYSWITCH-PLAIN-MX-1U; MX-1U
PGUP: KEYSWITCH-PLAIN-MX-1U; MX-1U
QUOTE: KEYSWITCH-PLAIN-MX-1U; MX-1U
RBRACKET: KEYSWITCH-PLAIN-MX-1U; MX-1U
RETURN: KEYSWITCH-PLAIN-MX-2U; MX-2U
RIGHT: KEYSWITCH-PLAIN-MX-1U; MX-1U
RIGHTCON: RIGHTCON; CON20
SEMIC: KEYSWITCH-PLAIN-MX-1U; MX-1U
SHIFT: KEYSWITCH-PLAIN-MX-2U; MX-2U
SPACE: KEYSWITCH-PLAIN-MX-2U; MX-2U
U: KEYSWITCH-PLAIN-MX-1U; MX-1U
UP: KEYSWITCH-PLAIN-MX-1U; MX-1U
VOLDOWN: KEYSWITCH-PLAIN-MX-1U; MX-1U
VOLUP: KEYSWITCH-PLAIN-MX-1U; MX-1U
Y: KEYSWITCH-PLAIN-MX-1U; MX-1U

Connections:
COL1: 7.MX1 (P0), F5.MX1 (P0), H.MX1 (P0), N.MX1 (P0), RIGHTCON.2, SPACE.MX1 (P0), Y.MX1 (P0)
COL2: 8.MX1 (P0), F6.MX1 (P0), J.MX1 (P0), M.MX1 (P0), RIGHTCON.4, U.MX1 (P0)
COL3: 9.MX1 (P0), COMMA.MX1 (P0), COMMAND.MX1 (P0), F7.MX1 (P0), I.MX1 (P0), K.MX1 (P0), RIGHTCON.6
COL4: 0.MX1 (P0), F8.MX1 (P0), L.MX1 (P0), O.MX1 (P0), PERIOD.MX1 (P0), RIGHTCON.8
COL5: DASH.MX1 (P0), F9.MX1 (P0), FSLASH.MX1 (P0), OPTION.MX1 (P0), P.MX1 (P0), RIGHTCON.10, SEMIC.MX1 (P0)
COL6: CONTROL.MX1 (P0), EQUALS.MX1 (P0), F10.MX1 (P0), LBRACKET.MX1 (P0), QUOTE.MX1 (P0), RIGHTCON.12
COL7: F11.MX1 (P0), RBRACKET.MX1 (P0), RIGHTCON.14
COL8: ANY.MX1 (P0), BSLASH.MX1 (P0), DELETE.MX1 (P0), F12.MX1 (P0), RETURN.MX1 (P0), RIGHTCON.16, SHIFT.MX1 (P0)
COL9: FDEL.MX1 (P0), INSERT.MX1 (P0), LEFT.MX1 (P0), MUTE.MX1 (P0), RIGHTCON.18
COL10: DOWN.MX1 (P0), END.MX1 (P0), HOME.MX1 (P0), RIGHTCON.20, UP.MX1 (P0), VOLDOWN.MX1 (P0)
COL11: PGDOWN.MX1 (P0), PGUP.MX1 (P0), RIGHT.MX1 (P0), RIGHTCON.19, VOLUP.MX1 (P0)
unnamed: DF5.A, F5.MX2 (P1)
unnamed: DF6.A, F6.MX2 (P1)
unnamed: DF7.A, F7.MX2 (P1)
unnamed: DF8.A, F8.MX2 (P1)
unnamed: DF9.A, F9.MX2 (P1)
unnamed: DF10.A, F10.MX2 (P1)
unnamed: DF11.A, F11.MX2 (P1)
unnamed: DF12.A, F12.MX2 (P1)
unnamed: DMUTE.A, MUTE.MX2 (P1)
unnamed: DVOLDOWN.A, VOLDOWN.MX2 (P1)
unnamed: DVOLUP.A, VOLUP.MX2 (P1)
unnamed: 7.MX2 (P1), D7.A
unnamed: 8.MX2 (P1), D8.A
unnamed: 9.MX2 (P1), D9.A
unnamed: 0.MX2 (P1), D0.A
unnamed: DASH.MX2 (P1), DDASH.A
unnamed: DEQUALS.A, EQUALS.MX2 (P1)
unnamed: DDELETE.A, DELETE.MX2 (P1)
unnamed: DINSERT.A, INSERT.MX2 (P1)
unnamed: DHOME.A, HOME.MX2 (P1)
unnamed: DPGUP.A, PGUP.MX2 (P1)
unnamed: DY.A, Y.MX2 (P1)
unnamed: DU.A, U.MX2 (P1)
unnamed: DI.A, I.MX2 (P1)
unnamed: DO.A, O.MX2 (P1)
unnamed: DP.A, P.MX2 (P1)
unnamed: DLBRACKET.A, LBRACKET.MX2 (P1)
unnamed: DRBRACKET.A, RBRACKET.MX2 (P1)
unnamed: BSLASH.MX2 (P1), DBSLASH.A
unnamed: DFDEL.A, FDEL.MX2 (P1)
unnamed: DEND.A, END.MX2 (P1)
unnamed: DPGDOWN.A, PGDOWN.MX2 (P1)
unnamed: DH.A, H.MX2 (P1)
unnamed: DJ.A, J.MX2 (P1)
unnamed: DK.A, K.MX2 (P1)
unnamed: DL.A, L.MX2 (P1)
unnamed: DSEMIC.A, SEMIC.MX2 (P1)
unnamed: DQUOTE.A, QUOTE.MX2 (P1)
unnamed: DRETURN.A, RETURN.MX2 (P1)
unnamed: DN.A, N.MX2 (P1)
unnamed: DM.A, M.MX2 (P1)
unnamed: COMMA.MX2 (P1), DCOMMA.A
unnamed: DPERIOD.A, PERIOD.MX2 (P1)
unnamed: DFSLASH.A, FSLASH.MX2 (P1)
unnamed: DSHIFT.A, SHIFT.MX2 (P1)
unnamed: DSPACE.A, SPACE.MX2 (P1)
unnamed: COMMAND.MX2 (P1), DCOMMAND.A
unnamed: DOPTION.A, OPTION.MX2 (P1)
unnamed: CONTROL.MX2 (P1), DCONTROL.A
unnamed: ANY.MX2 (P1), DANY.A
unnamed: DLEFT.A, LEFT.MX2 (P1)
unnamed: DDOWN.A, DOWN.MX2 (P1)
unnamed: DRIGHT.A, RIGHT.MX2 (P1)
unnamed: DUP.A, UP.MX2 (P1)
ROW1: DF5.C, DF6.C, DF7.C, DF8.C, DF9.C, DF10.C, DF11.C, DF12.C, DMUTE.C, DVOLDOWN.C, DVOLUP.C, RIGHTCON.1
ROW2: D0.C, D7.C, D8.C, D9.C, DDASH.C, DDELETE.C, DEQUALS.C, DHOME.C, DINSERT.C, DPGUP.C, RIGHTCON.11
ROW3: DBSLASH.C, DEND.C, DFDEL.C, DI.C, DLBRACKET.C, DO.C, DP.C, DPGDOWN.C, DRBRACKET.C, DU.C, DY.C, RIGHTCON.9
ROW4: DH.C, DJ.C, DK.C, DL.C, DQUOTE.C, DRETURN.C, DSEMIC.C, RIGHTCON.7
ROW5: DCOMMA.C, DFSLASH.C, DM.C, DN.C, DPERIOD.C, DSHIFT.C, DUP.C, RIGHTCON.5
ROW6: DANY.C, DCOMMAND.C, DCONTROL.C, DDOWN.C, DLEFT.C, DOPTION.C, DRIGHT.C, DSPACE.C, RIGHTCON.3

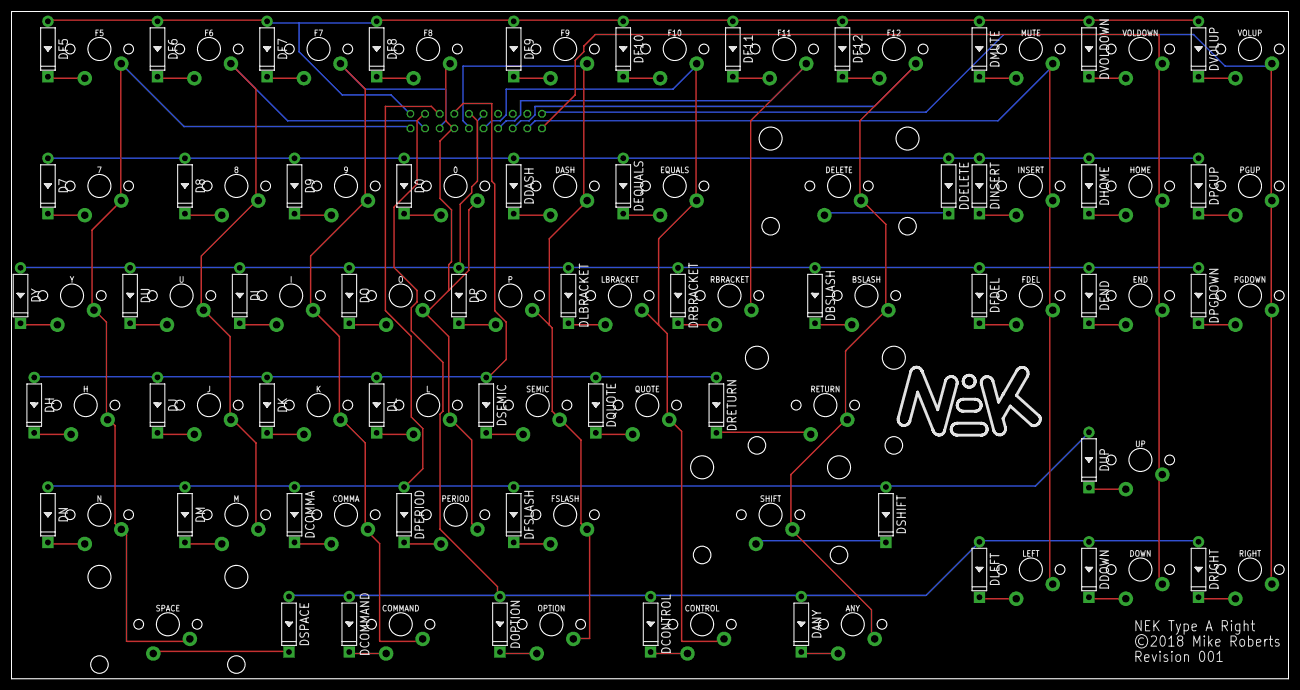
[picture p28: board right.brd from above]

Board: 2 copper layers, 222.0 x 116.0 mm, 109 parts (1 on the bottom side), 71 nets.

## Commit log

2018-04-20 basic body
    [body.scad]
2018-04-20 high left
    [body.scad]
2018-04-25 switch to bosl, quaternions are awesome
    [acme_screws.scad, beziers.scad, body.scad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]
2018-04-25 add slope
    [body.scad]
2018-04-26 filletted edges
    [body.scad]
2018-04-28 completish body
    [body.scad]
2018-04-29 right well start
    [body.scad, right_bottom.dxf, right_closed.dxf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]
2018-04-29 complete right well
    [body.scad]
2018-04-29 left well
    [body.scad, left_bottom.dxf, left_closed.dxf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]
2018-04-29 better corners
    [body.scad, left_bottom.dxf, left_closed.dxf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]
2018-04-29 decrease well size
    [body.scad]
2018-04-29 right wrist rest
    [adafruit_feather.stl, body.scad]
2018-04-29 left wrist
    [body.scad]
2018-04-29 pivot coord
    [body.scad]
2018-04-29 gap_x and gap_z
    [body.scad]
2018-04-29 finally, center polygon
    [body.scad]
2018-04-30 fix center poly
    [body.scad]
2018-04-30 right edge fillet
    [body.scad]
2018-04-30 fix center manifold
    [body.scad]
2018-04-30 top right fillet
    [body.scad]
2018-05-02 bottom right
    [body.scad]
2018-05-02 left edge
    [body.scad]
2018-05-02 left top and bottom
    [body.scad]
2018-05-02 left front corner
    [body.scad]
2018-05-02 better placement
    [body.scad]
2018-05-03 compute true split angle correctly
    [body.scad]
2018-05-03 back left corner
    [body.scad]
2018-05-03 right corners
    [body.scad]
2018-05-13 remove fillets
    [body.scad, test-bench.scad]
2018-05-13 better left fillets
    [body.scad]
2018-05-13 better right fillet
    [body.scad]
2018-05-13 hull all the things
    [body.scad]
2018-05-13 readd the wells
    [body.scad]
2018-05-13 new key layouts
    [body.scad, body.stl, left_bottom.dxf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]
2018-05-13 adjust y to get under 12"
    [body.scad, body.stl]
2018-06-15 fix spacing, docker
    [body.step]
2018-06-15 everything in python works and make!
    [body.step]
2018-06-17 mastery over planes
    [body.step]
2018-06-17 back with broken fillets
    [body.step]
2018-06-18 add stl
    [body.step, body.stl]
2018-06-18 move body to subdir
    [body.scad, body.step, body.stl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]
2018-06-18 remove bosl
    [acme_screws.scad, beziers.scad, involute_gears.scad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]
2018-06-26 basic svg import and extruding
    [body.step, body.stl]
2018-06-29 right top plate
    [body.step, body.stl]
2018-06-29 left top plate
    [body.step, body.stl]
2018-06-29 refactor python libs
    [body.step]
2018-06-29 fix right kbd error
    [body.step, body.stl, right_switch.dxf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]
2018-06-30 hollow bottoms
    [body.step, body.stl]
2018-06-30 readd back, fix cut throughs
    [body.step, body.stl]
2018-07-02 fillet top late cutouts
    [body.step, body.stl]
2018-07-02 smooth bottom
    [body.step, body.stl]
2018-07-05 refactor, todo
    [body.step]
2018-07-06 remove rounded back corners
    [body.step, body.stl]
2018-07-10 usb cutout, no screw hole
    [body.step, body.stl]
2018-07-11 refactor out coordplane
    [body.step, left_bottom.dxf, left_closed.dxf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]
2018-07-11 more refactoring
    [body.step]
2018-08-19 left schematic
    [left.sch]
2018-08-19 rows connected
    [left.sch]
2018-08-19 initial left board
    [left.brd]
2018-08-19 left routed
    [left.brd]
2018-08-19 completed left pcb
    [left.brd]
2018-08-30 better logo, right pcb
    [nek.dxf, right.brd, right.sch]
2018-09-04 move diodes away from stabilizers
    [left.brd, left.sch, right.brd]
2018-10-08 fix body errors
    [body.step]
2018-10-08 center board
    [body.step, body.stl, center.brd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]
2018-10-08 center rev 001
    [center.brd, center.sch]
2018-10-27 cavity fillet
    [body.step, body.stl]
2018-10-27 pcb mount
    [body.step, body.stl]
2018-10-27 plate mounting holes
    [adafruit_feather.stl, body.step, body.stl]
2018-10-27 power button
    [body.step, body.stl]
2018-10-27 bottom plate position
    [body.step, body.stl]
2018-10-27 bottom plate
    [body.step, body.stl]
2018-10-28 larger plates
    [body.step, body.stl]
2018-10-28 adjust fit
    [body.step, body.stl]
2018-10-28 export plate, make nonsense
    [body.step, body.stl, plate.step]
2018-10-28 update for washers
    [body.step, body.stl]
2018-10-28 cleanup, files for lasercutting, resolution
    [body.step, body.stl, plate.dxf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]
2018-10-29 convert points to arcs
    [body.step, body.stl, plate.step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]
2018-10-30 fix inner corners
    [body.step, body.stl, plate.step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]
2018-10-31 compute back plane height
    [body.step, body.stl, plate.step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]
2018-11-03 step down pockets
    [body.step, body.stl, plate.step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]
2018-11-06 fixes and hopefully final
    [body.step, body.stl, plate.dxf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]
2018-12-21 center rev 2
    [center.brd, center.sch]

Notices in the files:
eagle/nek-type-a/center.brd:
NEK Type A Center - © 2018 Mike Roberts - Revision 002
